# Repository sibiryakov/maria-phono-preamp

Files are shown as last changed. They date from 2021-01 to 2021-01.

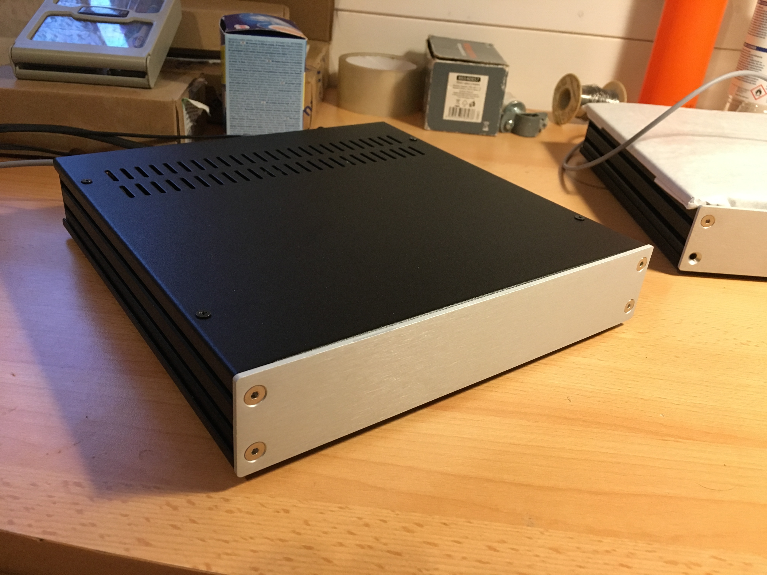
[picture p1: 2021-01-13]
drawings/case1.JPG

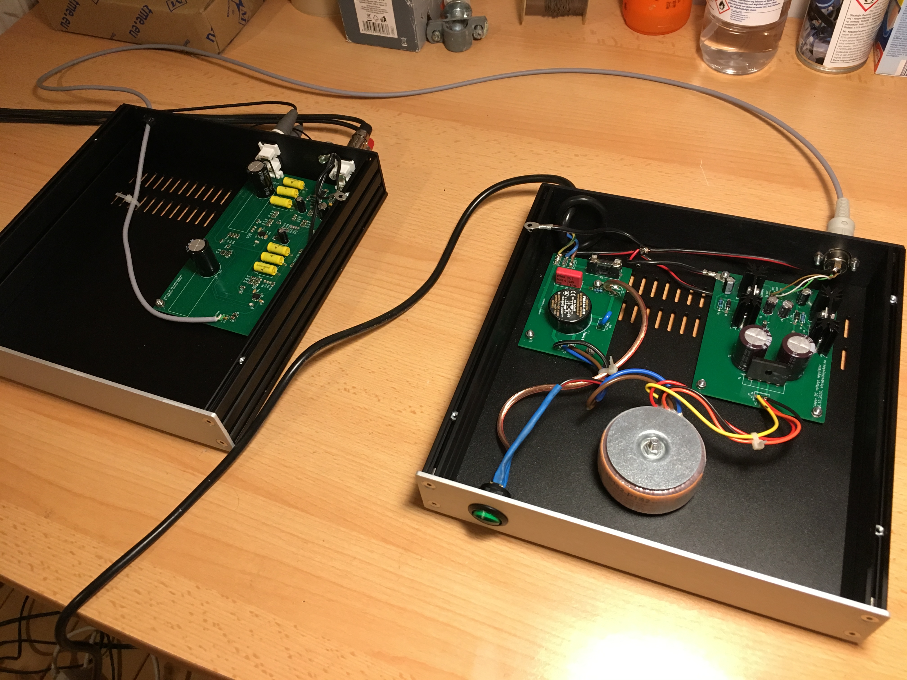
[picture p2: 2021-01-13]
drawings/two_cases3.JPG

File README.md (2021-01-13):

# Moving magnet phono preamp Maria

* Точность соответствия RIAA - 0.3 dB в среднем, 0.11 в интервале 125-8000 Гц,
* Поддерживаются только Moving Magnet (MM) картриджи,
* Усиление +30 dB, на частоте 1 kHz,
* Номинальное входное напряжение - 5 mV
* Входное сопротивление - 47 кОм
* Входная ёмкость - 100-470 пФ, впаивается пользователем
* Напряжение питания - +15В, -15В
* Потребляемый ток - ~100mA
* Максимальный уровень выходного сигнала 13В (25 dBu)
* THD на частоте 1 kHz - 0.004 %
* Шум, 1 kHz на уровне -120 dBu, 50hz   -100dbu
* Взаимное проникновение каналов 1 kHz (0 dBu)   -66 dBu

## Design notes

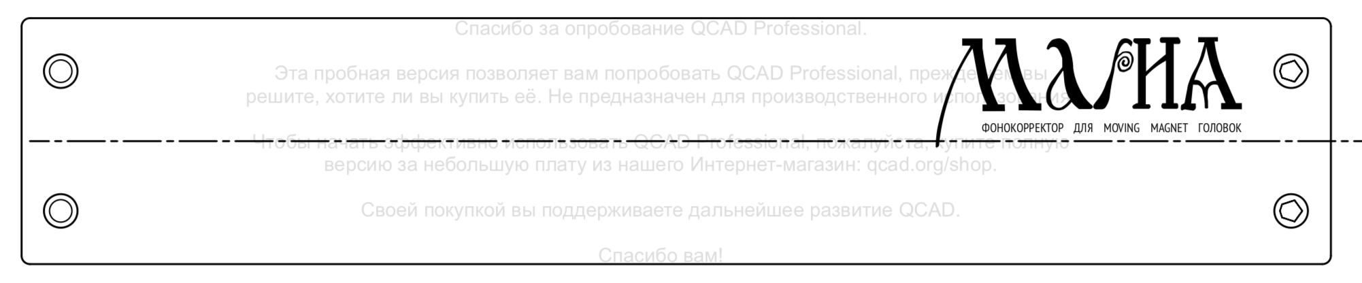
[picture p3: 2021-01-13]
drawings/front panel.png

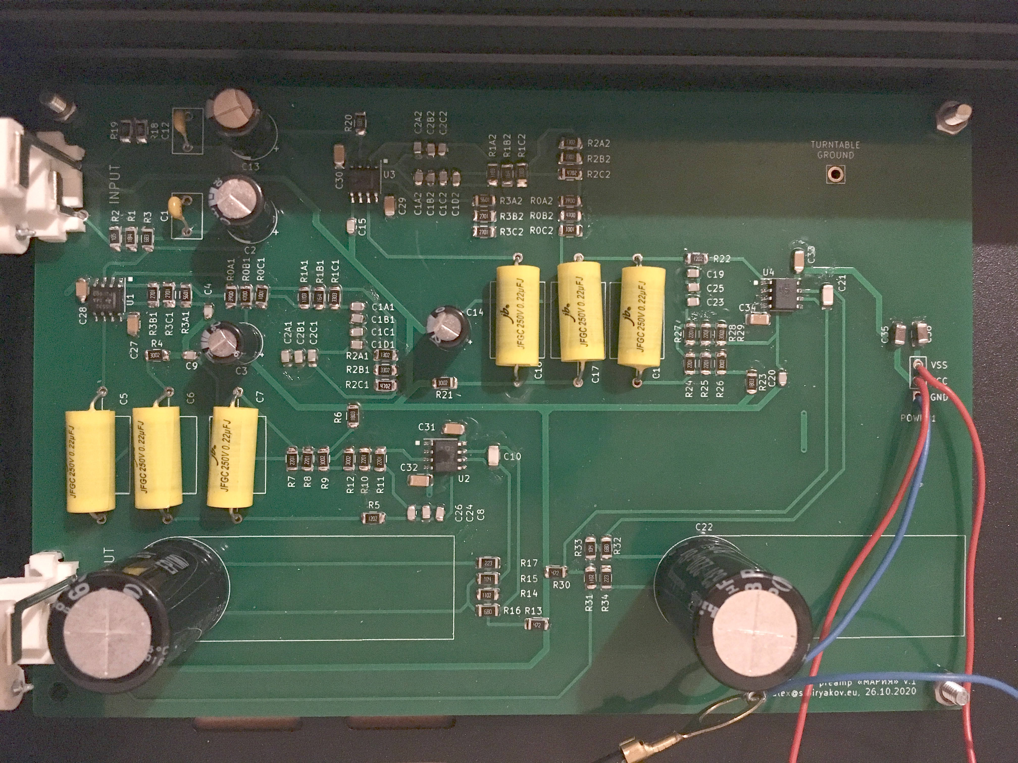
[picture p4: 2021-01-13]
drawings/photo pcb top.JPG

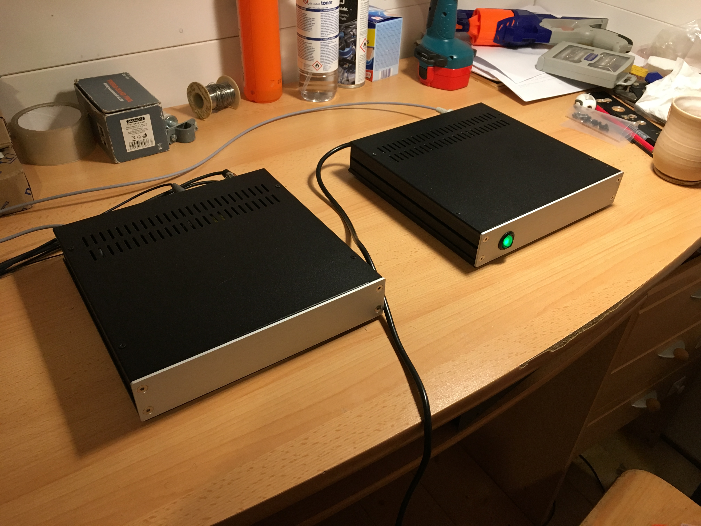
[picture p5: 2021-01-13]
drawings/two_cases2.JPG

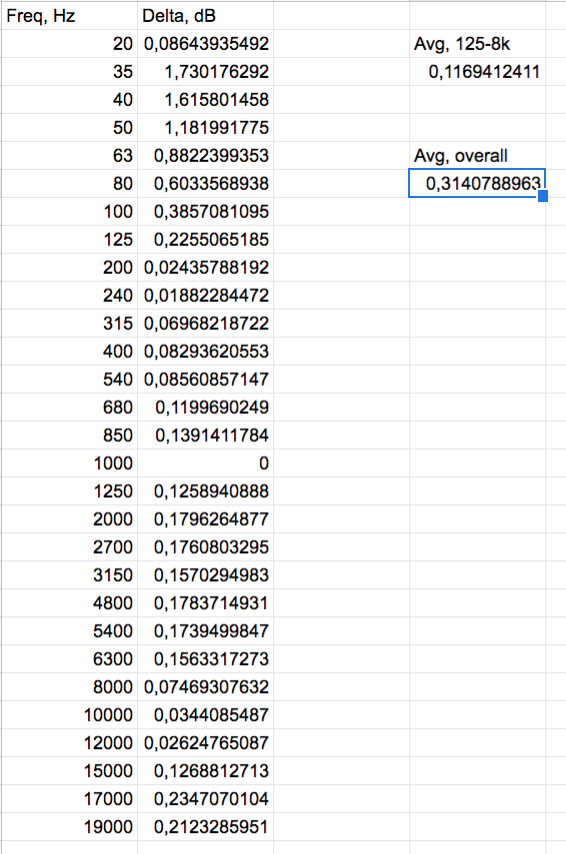
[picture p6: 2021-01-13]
drawings/RIAA deviation.png

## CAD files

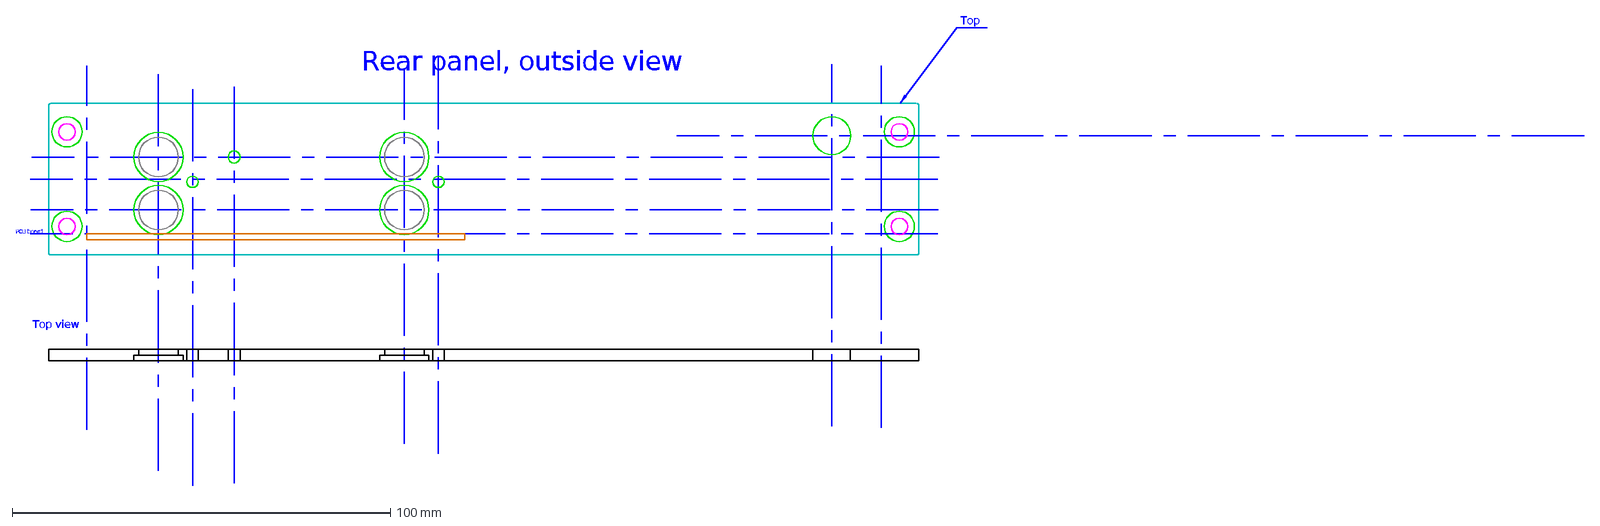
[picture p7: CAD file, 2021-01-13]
drawings/rear panel 1GX243.dxf
PCB board
Rear panel, outside view
Top view
Top

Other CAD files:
drawings/front panel graphic preamp.dxf
drawings/front panel graphic power supply.dxf

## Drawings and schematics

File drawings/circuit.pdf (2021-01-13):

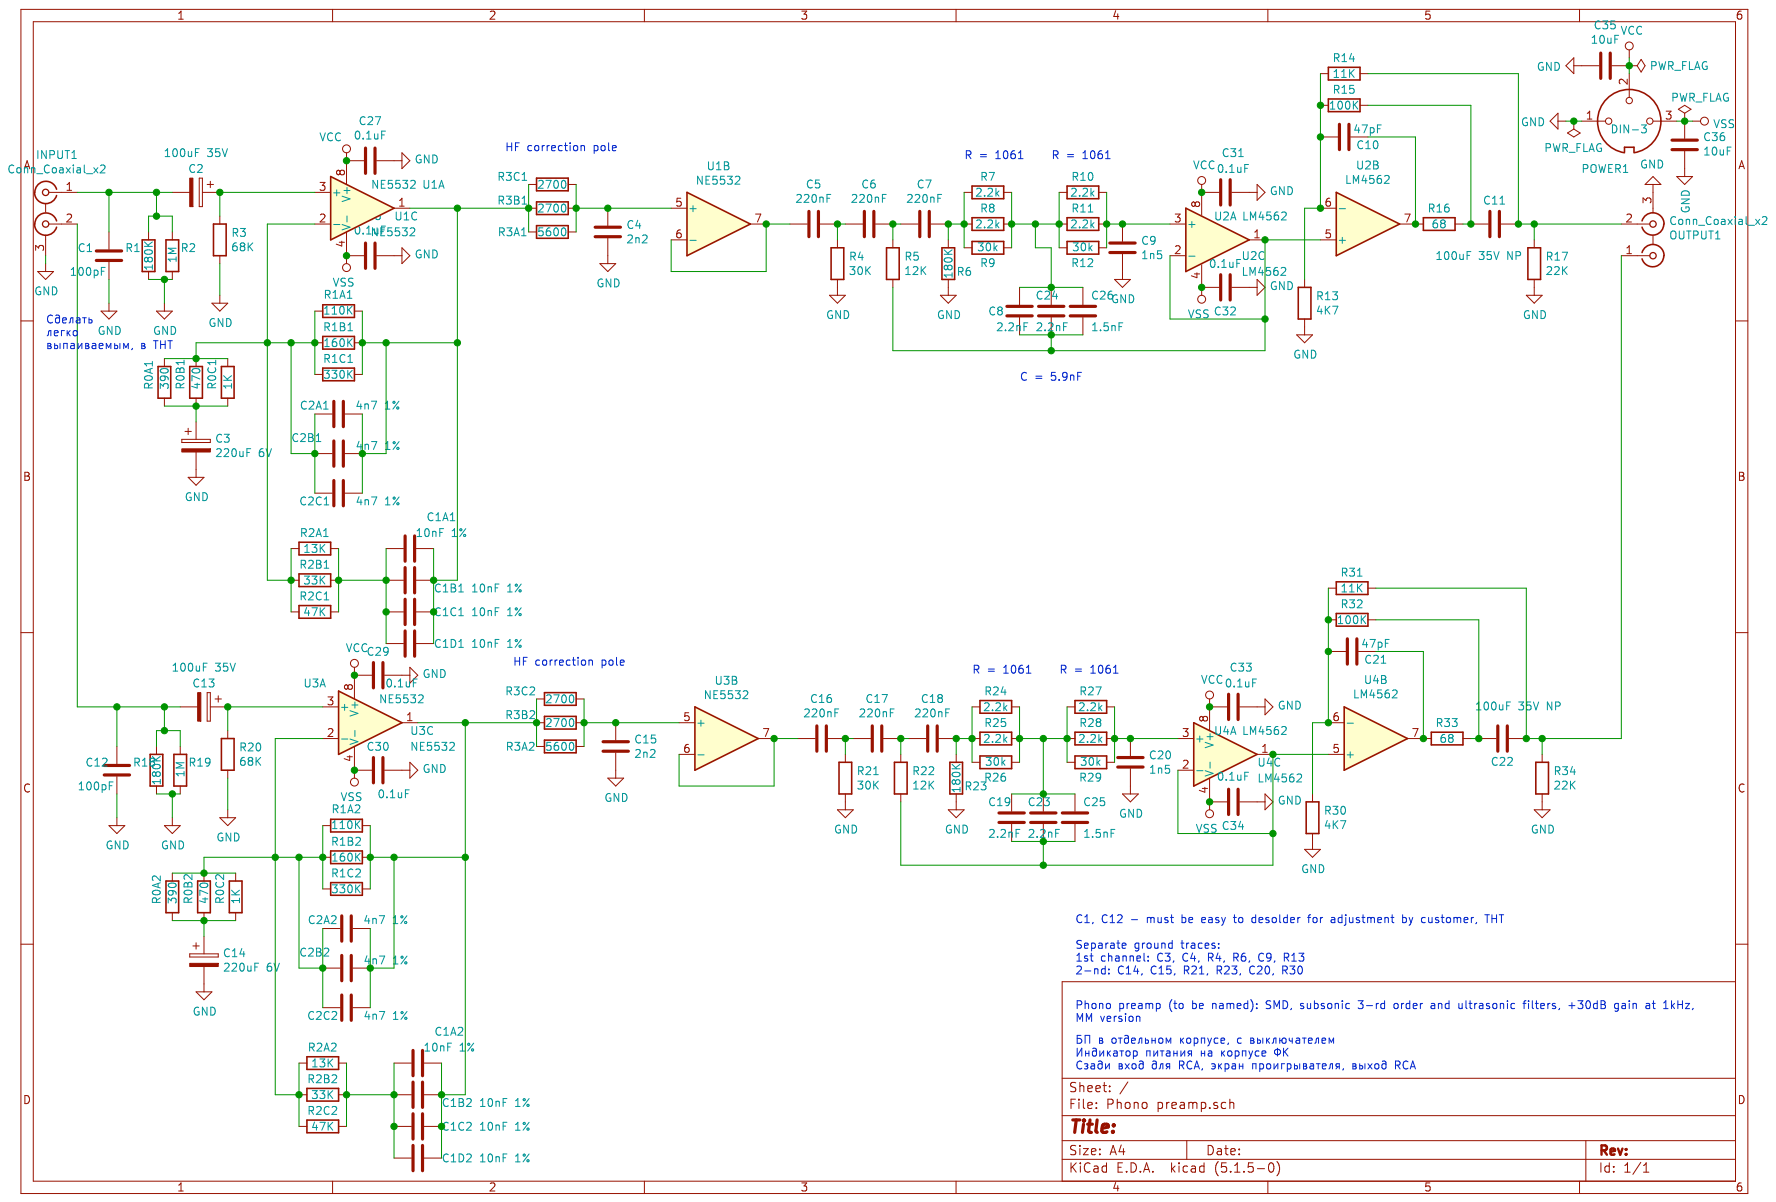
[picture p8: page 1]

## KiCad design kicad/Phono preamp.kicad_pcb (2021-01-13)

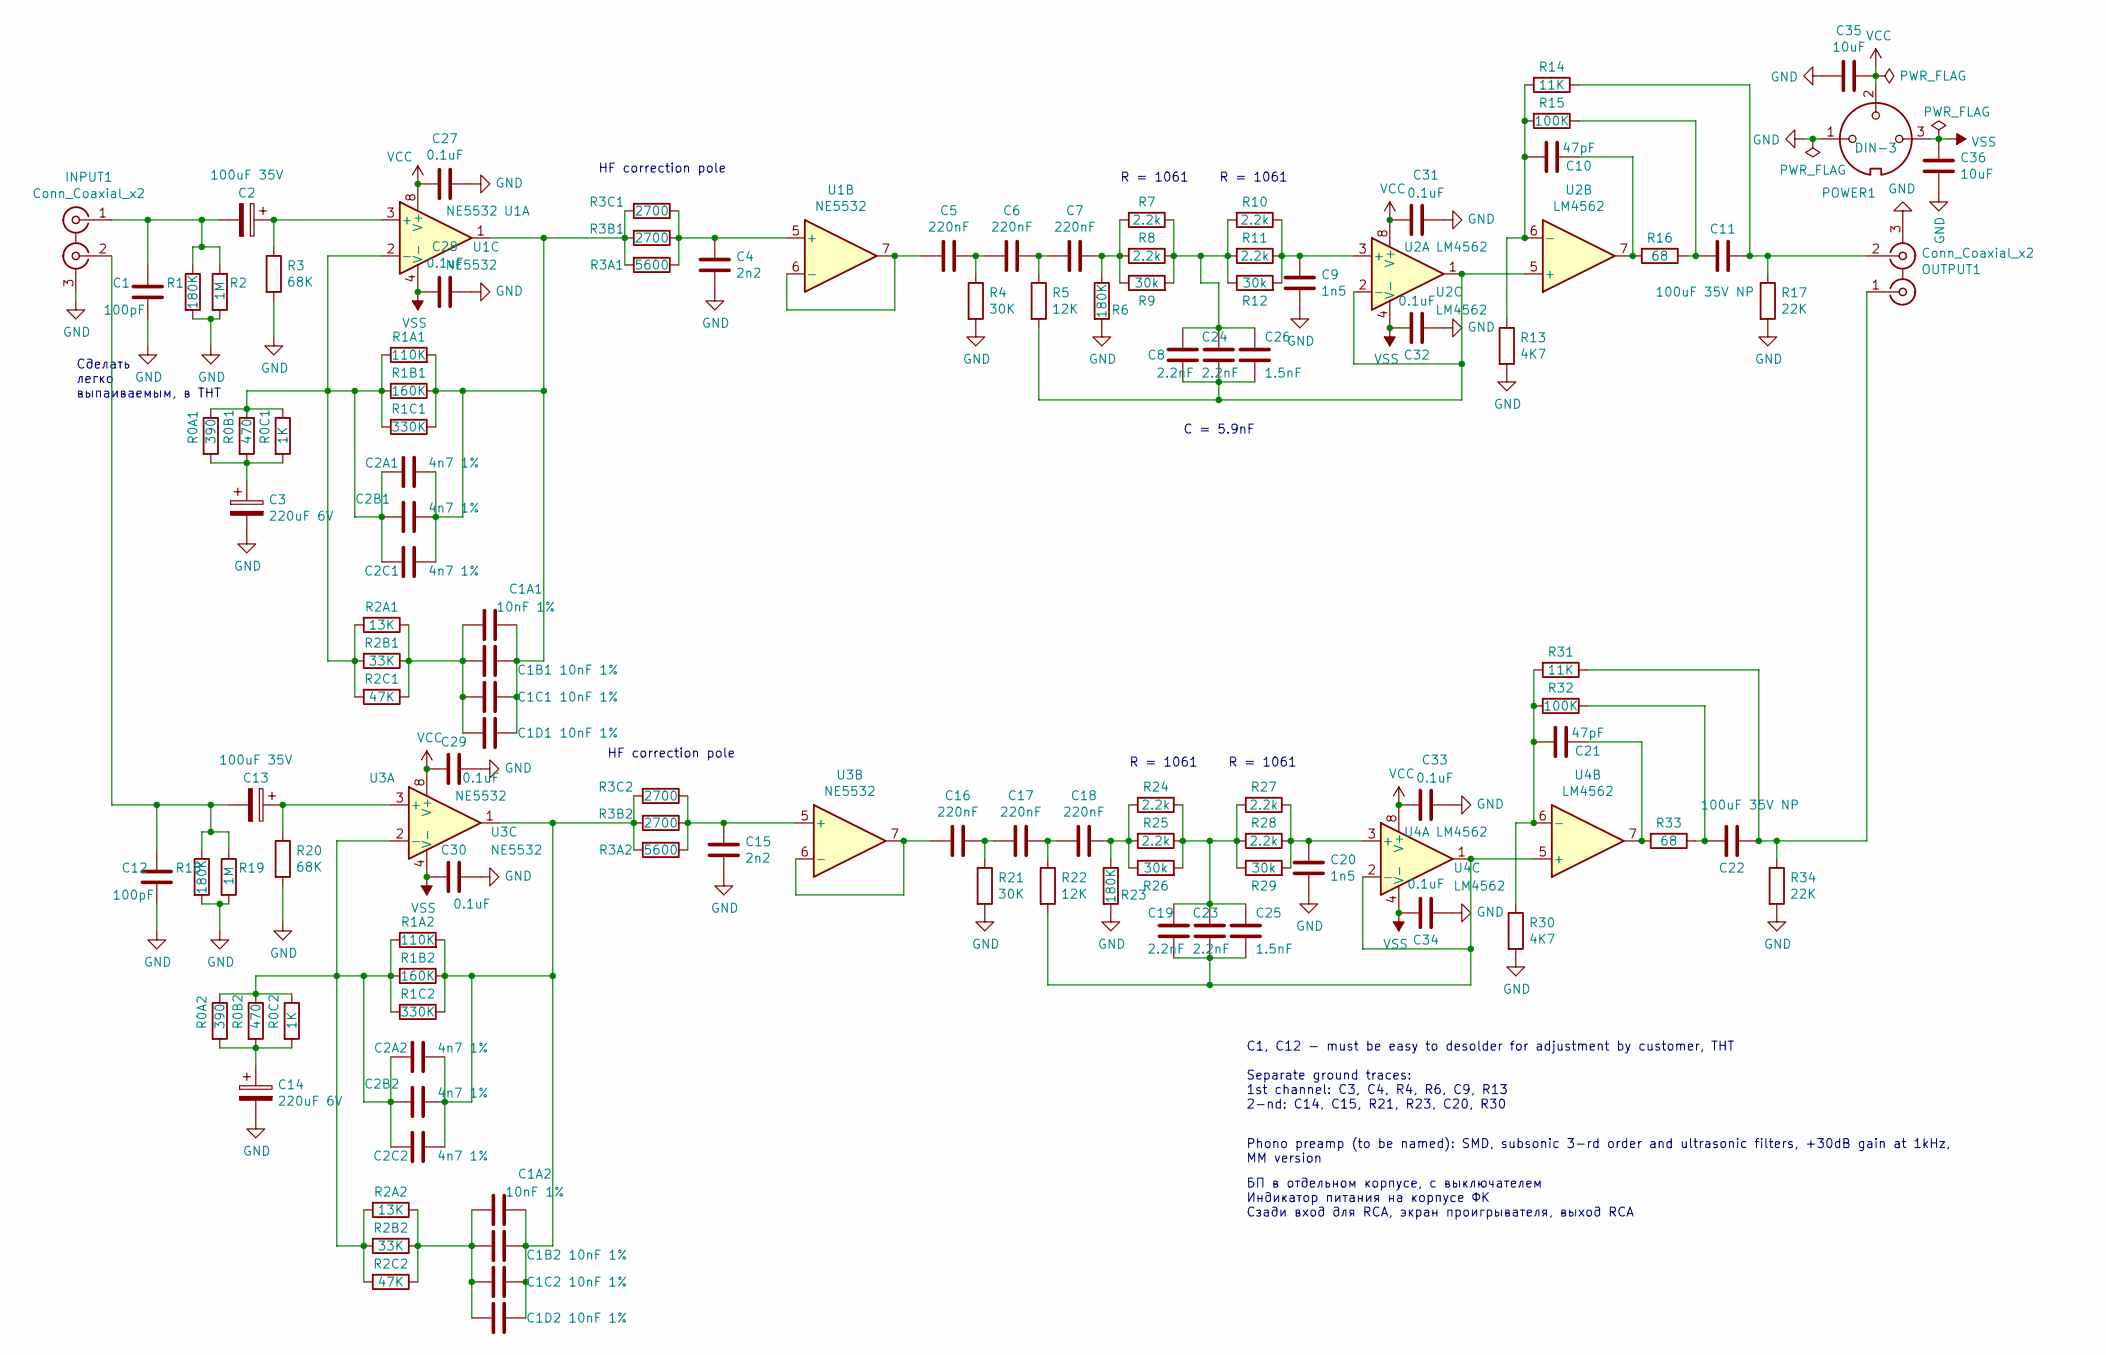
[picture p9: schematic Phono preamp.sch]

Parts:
C1, C12: 100pF; C_Rect_L7.0mm_W4.5mm_P5.00mm
C1A1, C1A2, C1B1, C1B2, C1C1, C1C2, C1D1, C1D2: 10nF 1%; C_0805_2012Metric
C2, C13: 100uF 35V; CP_Radial_D8.0mm_P5.00mm
C2A1, C2A2, C2B1, C2B2, C2C1, C2C2: 4n7 1%; C_0805_2012Metric
C3, C14: 220uF 6V; CP_Radial_D6.3mm_P2.50mm
C4, C15: 2n2; C_0805_2012Metric
C5, C6, C7, C16, C17, C18: 220nF; C_Axial_L12.0mm_D8.5mm_P20.00mm_Horizontal
C8, C19, C23, C24: 2.2nF; C_0805_2012Metric
C9, C20: 1n5; C_0805_2012Metric
C10, C21: 47pF; C_1206_3216Metric
C11, C22: 100uF 35V NP; C_Radial_D16.0mm_H25.0mm_P7.50mm
C25, C26: 1.5nF; C_0805_2012Metric
C27, C28, C29, C30, C31, C32, C33, C34: 0.1uF; C_1206_3216Metric
C35, C36: 10uF; C_1206_3216Metric
INPUT1: Conn_Coaxial_x2; RCA_8.3mm_CLIFF_FC68405_Horizontal
OUTPUT1: Conn_Coaxial_x2; RCA_8.3mm_CLIFF_FC68405_Horizontal
POWER1: DIN-3; PinHeader_1x03_P2.54mm_Vertical
R0A1, R0A2: 390; R_1206_3216Metric
R0B1, R0B2: 470; R_1206_3216Metric
R0C1, R0C2: 1K; R_1206_3216Metric
R1, R6, R18, R23: 180K; R_1206_3216Metric
R1A1, R1A2: 110K; R_1206_3216Metric
R1B1, R1B2: 160K; R_1206_3216Metric
R1C1, R1C2: 330K; R_1206_3216Metric
R2, R19: 1M; R_1206_3216Metric
R2A1, R2A2: 13K; R_1206_3216Metric
R2B1, R2B2: 33K; R_1206_3216Metric
R2C1, R2C2: 47K; R_1206_3216Metric
R3, R20: 68K; R_1206_3216Metric
R3A1, R3A2: 5600; R_1206_3216Metric
R3B1, R3B2, R3C1, R3C2: 2700; R_1206_3216Metric
R4, R21: 30K; R_1206_3216Metric
R5, R22: 12K; R_1206_3216Metric
R7, R8, R10, R11, R24, R25, R27, R28: 2.2k; R_1206_3216Metric
R9, R12, R26, R29: 30k; R_1206_3216Metric
R13, R30: 4K7; R_1206_3216Metric
R14, R31: 11K; R_1206_3216Metric
R15, R32: 100K; R_1206_3216Metric
R16, R33: 68; R_1206_3216Metric
R17, R34: 22K; R_1206_3216Metric
U1, U3: NE5532; SOIC-8_3.9x4.9mm_P1.27mm
U2, U4: LM4562; SOIC-8_3.9x4.9mm_P1.27mm

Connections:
GND: C1.2, C3.2, C4.2, C9.2, C12.2, C14.2, C15.2, C20.2, C27.1, C28.1, C29.1, C30.1, C31.1, C32.1, C33.1, C34.1, C35.1, C36.1, INPUT1.3 (EXT), OUTPUT1.3 (EXT), POWER1.1, R1.2, R2.2, R3.2, R4.2, R6.2, R13.2, R17.2, R18.2, R19.2, R20.2, R21.2, R23.2, R30.2, R34.2
unnamed: C1.1, C2.2, INPUT1.1 (IN1), R1.1, R2.1
unnamed: C1A1.1, C1B1.1, C1C1.1, C1D1.1, C2A1.2, C2B1.1, C2C1.1, R1A1.2, R1B1.1, R1C1.1, R3A1.2, R3B1.2, R3C1.2, U1.1
unnamed: C1A1.2, C1B1.2, C1C1.2, C1D1.2, R2A1.1, R2B1.1, R2C1.1
unnamed: C1A2.1, C1B2.1, C1C2.1, C1D2.1, C2A2.2, C2B2.1, C2C2.1, R1A2.2, R1B2.1, R1C2.1, R3A2.2, R3B2.2, R3C2.2, U3.1
unnamed: C1A2.2, C1B2.2, C1C2.2, C1D2.2, R2A2.1, R2B2.1, R2C2.1
unnamed: C2.1, R3.1, U1.3 (+)
unnamed: C2A1.1, C2B1.2, C2C1.2, R0A1.1, R0B1.1, R0C1.1, R1A1.1, R1B1.2, R1C1.2, R2A1.2, R2B1.2, R2C1.2, U1.2 (-)
unnamed: C2A2.1, C2B2.2, C2C2.2, R0A2.1, R0B2.1, R0C2.1, R1A2.1, R1B2.2, R1C2.2, R2A2.2, R2B2.2, R2C2.2, U3.2 (-)
unnamed: C3.1, R0A1.2, R0B1.2, R0C1.2
unnamed: C4.1, R3A1.1, R3B1.1, R3C1.1, U1.5 (+)
unnamed: C5.1, C6.2, R4.1
unnamed: C5.2, U1.6 (-), U1.7
unnamed: C6.1, C7.2, R5.1
unnamed: C7.1, R6.1, R7.2, R8.2, R9.1
unnamed: C9.1, R10.1, R11.1, R12.2, U2.3 (+)
unnamed: C10.1, R16.2, U2.7
unnamed: C10.2, R13.1, R14.2, R15.2, U2.6 (-)
unnamed: C11.1, OUTPUT1.2 (IN2), R14.1, R17.1
unnamed: C11.2, R15.1, R16.1
unnamed: C12.1, C13.2, INPUT1.2 (IN2), R18.1, R19.1
unnamed: C13.1, R20.1, U3.3 (+)
unnamed: C14.1, R0A2.2, R0B2.2, R0C2.2
unnamed: C15.1, R3A2.1, R3B2.1, R3C2.1, U3.5 (+)
unnamed: C16.1, C17.2, R21.1
unnamed: C16.2, U3.6 (-), U3.7
unnamed: C17.1, C18.2, R22.1
unnamed: C18.1, R23.1, R24.2, R25.2, R26.1
unnamed: C19.1, C23.1, C25.1, R24.1, R25.1, R26.2, R27.2, R28.2, R29.1
unnamed: C19.2, C23.2, C25.2, R22.2, U4.1, U4.2 (-), U4.5 (+)
unnamed: C20.1, R27.1, R28.1, R29.2, U4.3 (+)
unnamed: C21.1, R33.2, U4.7
unnamed: C21.2, R30.1, R31.2, R32.2, U4.6 (-)
unnamed: C22.1, R32.1, R33.1
unnamed: C22.2, OUTPUT1.1 (IN1), R31.1, R34.1
unnamed: C8.1, C24.1, C26.1, R7.1, R8.1, R9.2, R10.2, R11.2, R12.1
unnamed: C8.2, C24.2, C26.2, R5.2, U2.1, U2.2 (-), U2.5 (+)
VCC: C27.2, C29.2, C31.2, C33.2, C35.2, POWER1.2, U1.8 (V+), U2.8 (V+), U3.8 (V+), U4.8 (V+)
VSS: C28.2, C30.2, C32.2, C34.2, C36.2, POWER1.3, U1.4 (V-), U2.4 (V-), U3.4 (V-), U4.4 (V-)

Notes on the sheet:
Phono preamp (to be named): SMD, subsonic 3-rd order and ultrasonic filters, +30dB gain at 1kHz, MM version
HF correction pole
Сделать легко выпаиваемым, в THT
БП в отдельном корпусе, с выключателем Индикатор питания на корпусе ФК Сзади вход для RCA, экран проигрывателя, выход RCA
R = 1061
C = 5.9nF
C1, C12 - must be easy to desolder for adjustment by customer, THT Separate ground traces: 1st channel: C3, C4, R4, R6, C9, R13 2-nd: C14, C15, R21, R23, C20, R30

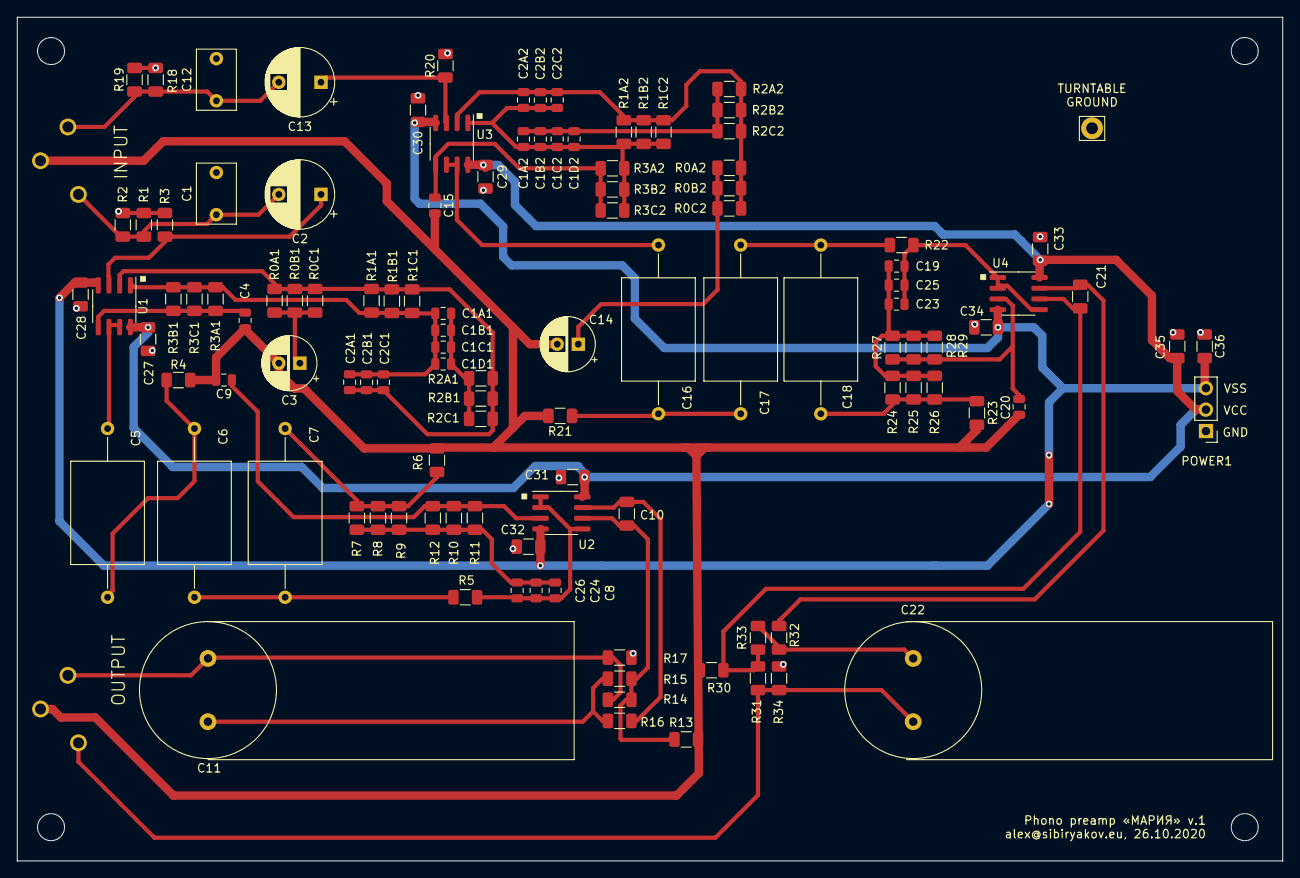
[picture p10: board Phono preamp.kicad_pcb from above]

Board: 2 copper layers, 150.0 x 100.0 mm, 115 parts (0 on the bottom side), 39 nets.

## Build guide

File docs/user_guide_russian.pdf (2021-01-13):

# Фонокорректор “Мария”

# , для MM-картриджей: руководство пользователя

## Введение

Поздравляю! Вы избранный (-ая). Это изделие делалось ограниченной серией для самых близких мне людей. В свете современных тенденций производства, когда производители экономят на всём, я решил, что качественно сделанный фонокорректор будет очень кстати. Что значит качественный?
- Питание +/- 15В, даёт максимальное напряжение на выходе 13В (RMS), это соответствует максимальному уровню 25 dBu. Это гарантирует воспроизведение громких звуков без срезов
- Высокая точность соответствия стандарту RIAA, отклонение в среднем +/- 0.3 dB. Обеспечивает точность передачи записанной программы
- В блоке питания используются конденсаторы с большим ресурсом
- Низкий шум: -100 dBu на 50 Hz, -120 dBu на 1 kHz. На 50 Гц, это достигается размещением блока питания в отдельном корпусе
- Оловянно-свинцовый припой (вопреки нормам ЕС), гарантирует отсутствие роста кристаллов олова. Это вклад в надёжность схемы
- Компоненты малого размера, SMD 0805, 1206, в целях минимизации помех
- Фильтрация высоких частот перед блоком питания. Гарантирует надёжную работу схемы
- Исполнение в виде двух, стильных, алюминиевых корпусов, сделано в Италии
- Ремесленное производство: ручная сборка и тестирование

Также схемотехника использует несколько решений, которые, возможно, не будут приняты самыми заядлыми аудиофилами. Ниже они перечислены вместе с причинами.

- Коэффициент усиления -30 dB, на частоте 1 kHz. Это минимальный достаточный уровень для усилителей мощности, и оставляет большой запас по максимальному уровню. Иными словами clipping сведён к минимуму.
- Поддержка только MM картриджей. Никто из будущих владельцев не имел MC.
- IEC поправка не реализована. Это дискуссионный вопрос, нужна ли она вообще.
- Всегда включенный активный суб-звуковой фильтр Баттерворта третьего порядка. Для фильтрации помех от резонанса плеча тонарма и двигателя.

В целом я стремился сделать надёжно и качественно с минимальными затратами. Поэтому иногда используются не самые эргономичные решения. Документация содержит сервисный раздел, это позволит провести обслуживание в любой мастерской в будущем.

# Рекомендации по использованию

## Впаять входной конденсатор соответствующий картриджу

Актуально, если я этого не сделал для Вас, или Вы поменяли картридж. На плате ФК это C12 и C1, вблизи входного разъёма. Смотрите рекомендуемую нагрузку картриджа, и впаивайте соответствующий керамический конденсатор. Это нужно для нормальной АЧХ на всём диапазоне частот.

## Размещать корпус БП на расстоянии 1м от корпуса ФК

Корпус ФК очень чувствителен к помехам электросети, не размещайте вблизи силовые кабеля, блок питания ФК и другие блоки питания. Достаточно расстояния 1 метр. Главная проблема это электромагнитные помехи в трансформаторах, приводящие к помехам на 50 Гц.

## Коммутацию производить при отключенном питании

Во избежании повреждения акустических систем и усилителей.

## Используйте короткий кабель проигрывателя и разъёмы высокого качества

Это тот момент, когда кабеля действительно влияют на качество звука. Качественный кабель и разъёмы должны быть экранированы, не вносить чрезмерную ёмкость. Поэтому рекомендую заменить штатные разъёмы и кабель проигрывателя, если есть сомнение. Например есть разъёмы Amphenol, Neutrik, и кабеля TASKER, Sommer Cable.

## Не допускайте касания корпуса входными разъёмами

Некоторые широкие разъёмы могут касаться корпуса при подключении ко входу, лучше оставлять зазор.

# Спецификации

- Точность соответствия RIAA - 0.3 dB в среднем, 0.11 в интервале 125-8000 Гц,
- Поддерживаются только Moving Magnet (MM) картриджи,
- Усиление +30 dB, на частоте 1 kHz,
- Номинальное входное напряжение - 5 mV
- Входное сопротивление - 47 кОм
- Входная ёмкость - 100-470 пФ, впаивается пользователем

- Напряжение питания - +15В, -15В
- Входное напряжение - 220-230В
- Потребляемый ток - 0.4A
- Максимальный уровень выходного сигнала 13В (25 dBu)
- THD на частоте 1 kHz - 0.004 %
- Шум, 1 kHz на уровне -120 dBu, 50hz -100dbu
- Взаимное проникновение каналов 1 kHz (0 dBu) -66 dBu

# Графики

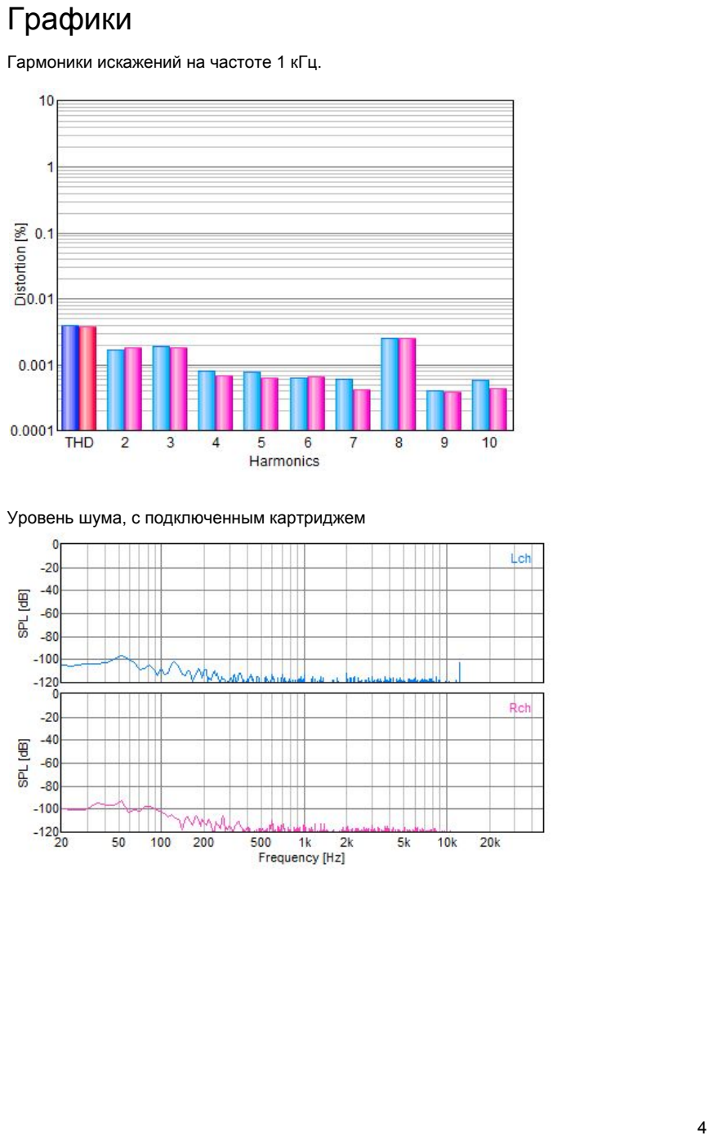
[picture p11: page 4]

Гармоники искажений на частоте 1 кГц.

Уровень шума, с подключенным картриджем

Точность соответствия стандарту RIAA, в зависимости от частоты

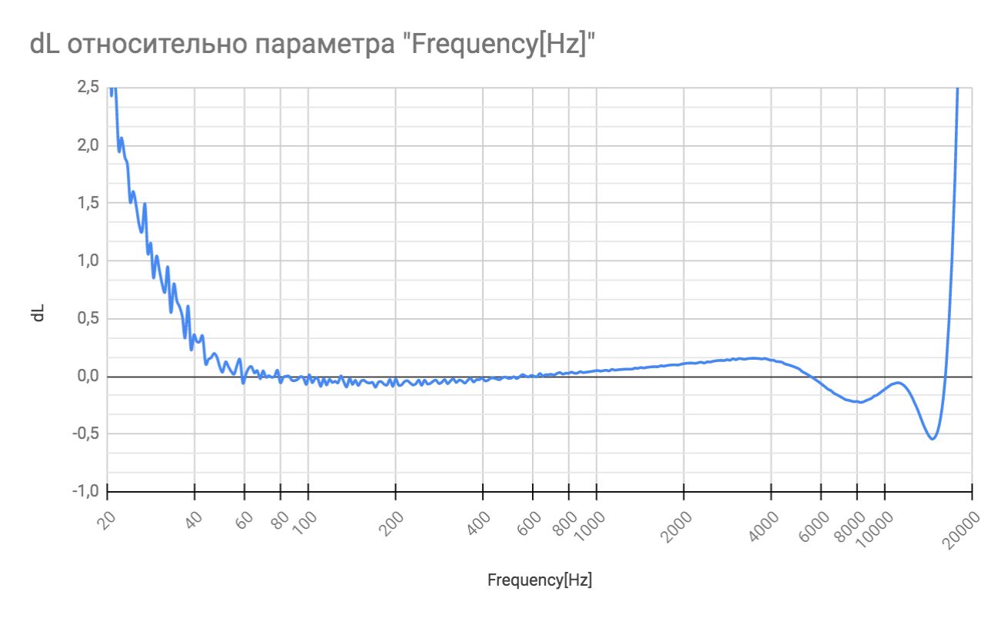
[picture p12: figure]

Скачок на низких частотах связан с суб-звуковым фильтром низких частот 3-го порядка, он не специфицируется в стандарте RIAA. К сожалению, в этой методологии на ВЧ очень высокая ошибка, вероятно, реальная точность выше.

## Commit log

2021-01-13 drawings, schematic, pcb
    [Phono preamp-B_Cu.gbr, Phono preamp-B_Mask.gbr, Phono preamp-B_Paste.gbr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]
2021-01-13 RCA connector Footprint
